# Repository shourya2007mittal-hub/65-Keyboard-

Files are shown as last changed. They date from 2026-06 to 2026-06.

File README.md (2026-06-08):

# 65-Keyboard-



I am building a 65% layout keyboard based on Seed Studio Xiao nrf52840 also It will have a 3.7v battery and an 0.91 inch OLED Screen. Switches will be HotSwapable. I used expander to connect the rows and coluns because there weren't enough pins available.

## Features
-  nrf52840 Rp2040
- uses 65% Keyboard Layout 
-  Uses Keyboard Matrix
-  Had a rotor encoder and an 0.91 inch oled screen

  | Item | Price | Source |
|------|------:|--------|
| PCB + Shipping - Coupons | 25.14 | JLCPCB |
| KeyCaps | 15.04 | https://meckeys.com/shop/accessories/keyboard-accessories/keycaps/gengar-anime-keycap-set/ |
| Hot-swap (pack of 10) × 7 | 5.50 | https://meckeys.com/shop/accessories/keyboard-accessories/key-switches/kailh-hot-swap-socket/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 |
| Switches (pack of 10) × 7 | 22.10 | https://meckeys.com/shop/accessories/keyboard-accessories/key-switches/hmx-xinhai-switch/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 |
| Stabilizers | 10.76 | https://meckeys.com/shop/accessories/keyboard-accessories/more/glorious-goat-stabilizers/ |
| Meckeys Shipping | 1.10 | https://meckeys.com |
| Expander × 2 | 6.22 | https://robu.in/product/pca9555dwr-texas-instruments-400khz-soic-24-300mil-i-o-expanders-rohs/ |
| XIAO BLE nRF52840 | 12.40 | https://robu.in/product/seeed-studio-xiao-ble-nrf52840/ |
| On-Off Switch | 1.12 | https://robu.in/product/os202011ma0qn1-ck-100ma-dpdt-12v-10000-times-plugin-slide-switches-rohs/ |
| 2MΩ Resistor | 0.13 | https://robu.in/product/crcw12062m20fkea-vishay-smd-chip-resistor-2-2-mohm-%c2%b1-1-250-mw-1206-3216-metric-thick-film-general-purpose/ |
| 806kΩ Resistor | 0.13 | https://robu.in/product/rc0402fr-07806kl-yageo-smd-chip-resistor-806-kohm-%c2%b1-1-63-mw-0402-1005-metric-thick-film-general-purpose/ |
| Robu Shipping | 1.10 | https://robu.in |
| Solder Paste for SMD Components | 2.70 | https://www.amazon.in/gp/product/B0GY879KCL/ |
| 1N4148W-T4 Diodes (Pack of 15) × 5 ( used amazon beacuse wasn't avilable anywhere else)| 11.78 | https://www.amazon.in/gp/product/B0FZL2D1GG/ |
| **Total** | **115.22** | |

### Schematic<br><br>



###  PCB Design<br><br>




### 3D Render <br><br>
Screenshot 2026-06-08 170318 - Copy




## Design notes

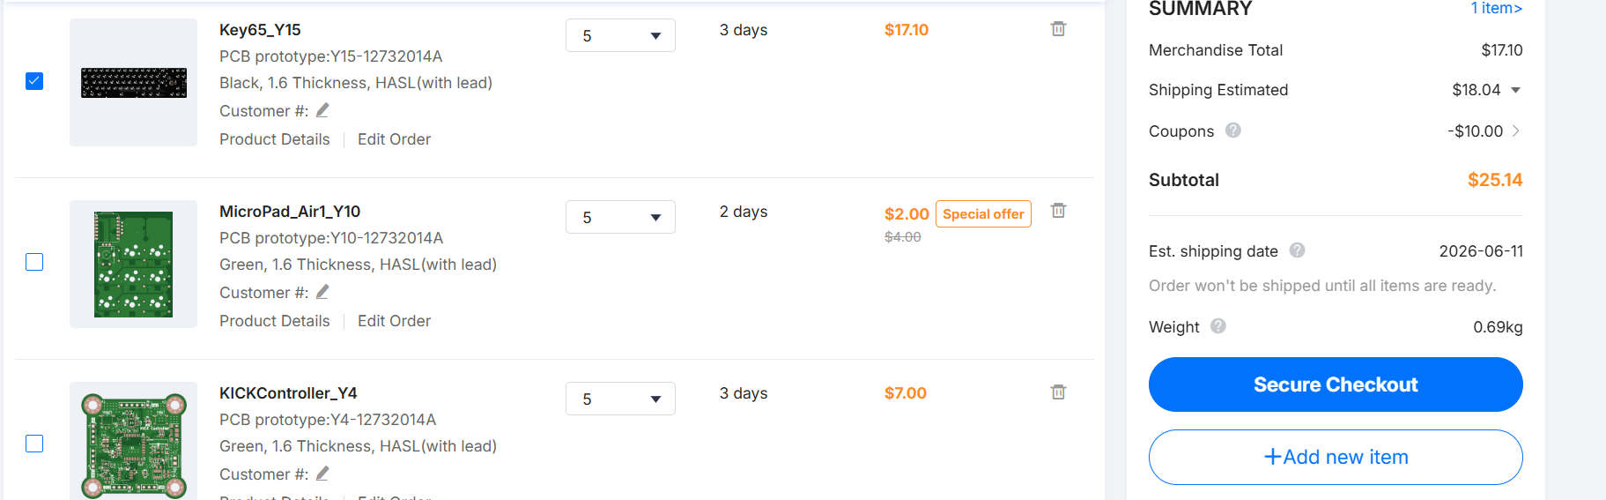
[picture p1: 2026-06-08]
Payout Screenshot/Screenshot 2026-06-08 213410.png

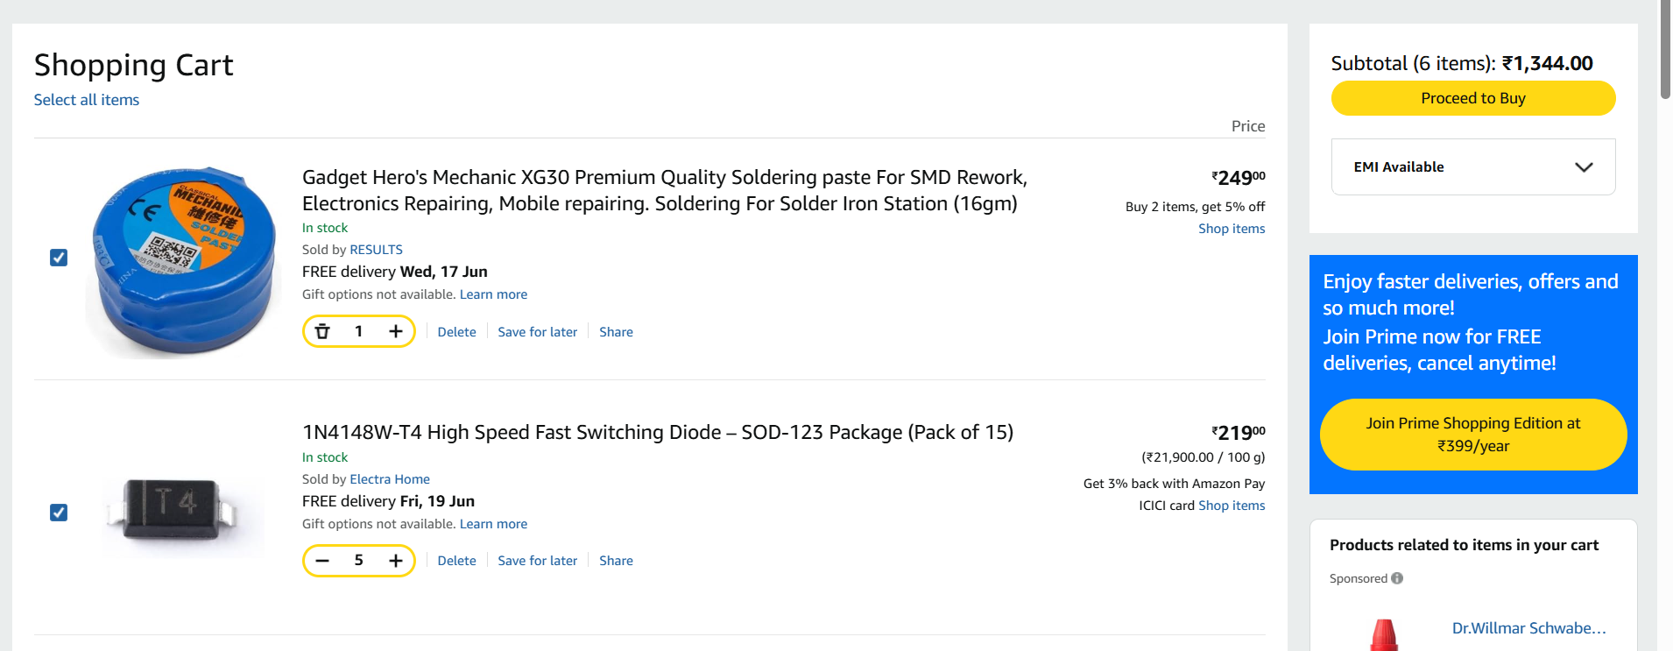
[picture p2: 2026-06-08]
Payout Screenshot/Screenshot 2026-06-08 214906.png

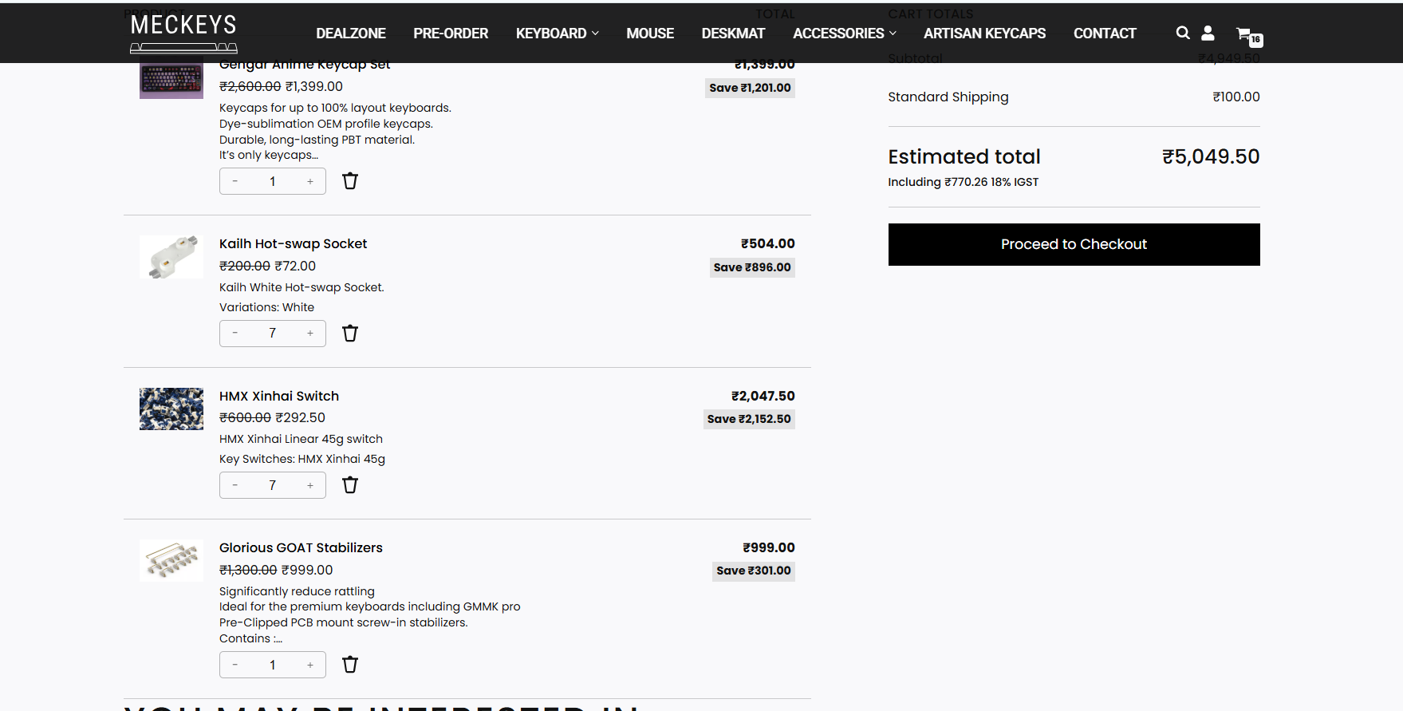
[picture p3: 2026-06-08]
Payout Screenshot/Screenshot 2026-06-08 215119.png

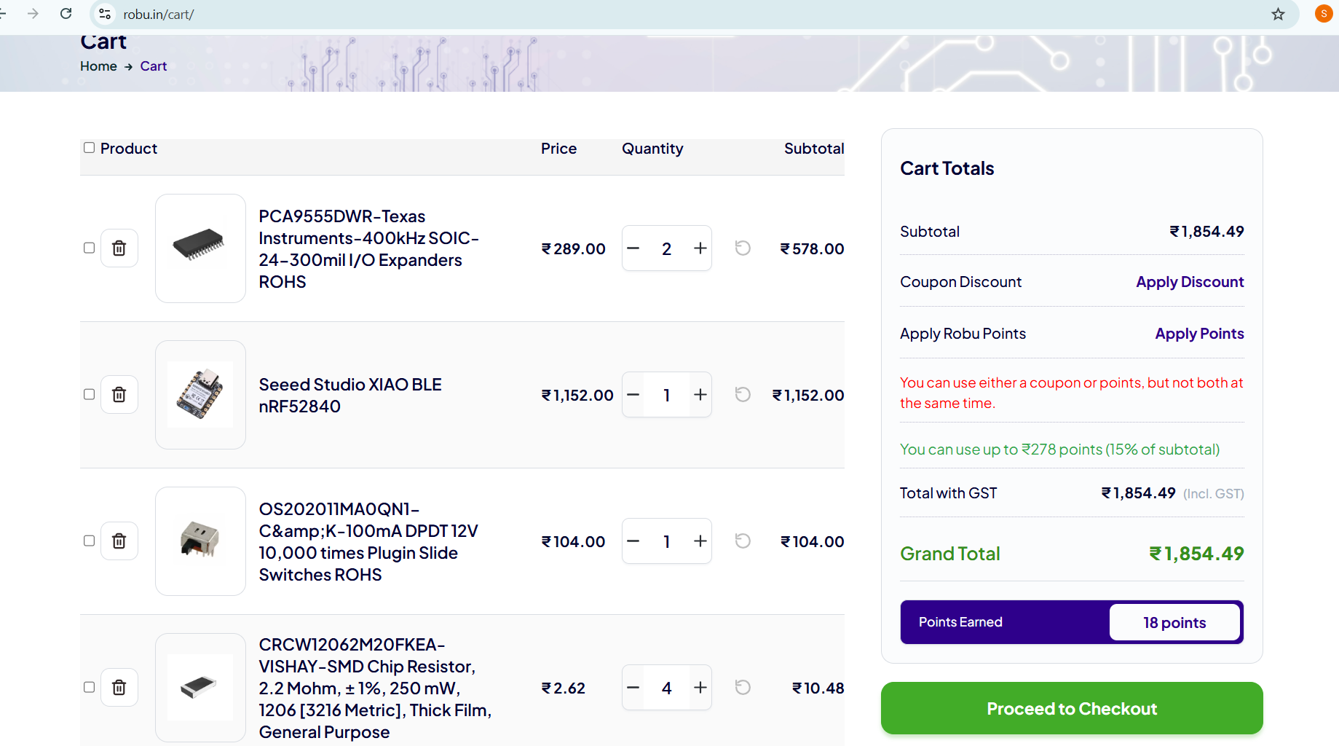
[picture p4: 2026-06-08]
Payout Screenshot/Screenshot 2026-06-08 215139.png

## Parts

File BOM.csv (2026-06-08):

Item | Price | Source
PCB + Shipping - Coupons | 25.14 | JLCPCB
KeyCaps | 15.04 | https://meckeys.com/shop/accessories/keyboard-accessories/keycaps/gengar-anime-keycap-set/
Hot-swap (pack of 10) x7 | 5.5 | https://meckeys.com/shop/accessories/keyboard-accessories/key-switches/kailh-hot-swap-socket/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
Switches (pack of 10) x 7 | 22.1 | https://meckeys.com/shop/accessories/keyboard-accessories/key-switches/hmx-xinhai-switch/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
Stabilizers | 10.76 | https://meckeys.com/shop/accessories/keyboard-accessories/more/glorious-goat-stabilizers/
Meckey shipping | 1.1 | meckeys.com
Expander x 2 | 6.22 | https://robu.in/product/pca9555dwr-texas-instruments-400khz-soic-24-300mil-i-o-expanders-rohs/
XIAO BLE nRF52840 | 12.4 | https://robu.in/product/seeed-studio-xiao-ble-nrf52840/
On-Off switch | 1.12 | https://robu.in/product/os202011ma0qn1-ck-100ma-dpdt-12v-10000-times-plugin-slide-switches-rohs/
2M OHM Resistor | 0.13 | https://robu.in/product/crcw12062m20fkea-vishay-smd-chip-resistor-2-2-mohm-%c2%b1-1-250-mw-1206-3216-metric-thick-film-general-purpose/
806k resistor | 0.13 | https://robu.in/product/rc0402fr-07806kl-yageo-smd-chip-resistor-806-kohm-%c2%b1-1-63-mw-0402-1005-metric-thick-film-general-purpose/
Robu shipping | 1.1 | robu.in
Solder Paste for SND components | 2.7 | https://www.amazon.in/gp/product/B0GY879KCL/ref=ox_sc_act_title_1?smid=A2TAUOL95KBX1X&psc=1
1N4148W-T4 diodes (Pack of 15) X 5 ( used amazon beacuse wasn't avilable anywhere else) | 11.78 | https://www.amazon.in/gp/product/B0FZL2D1GG/ref=ox_sc_act_title_2?smid=A28WR0HSDEABON&psc=1
Total | 115.2

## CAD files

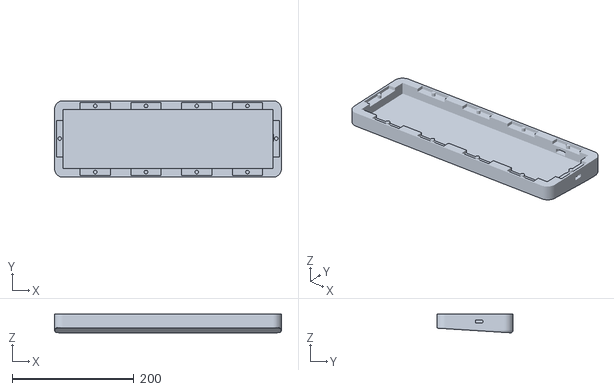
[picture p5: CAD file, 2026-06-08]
Production/Base.stl
372.9 x 125.6 x 30.8

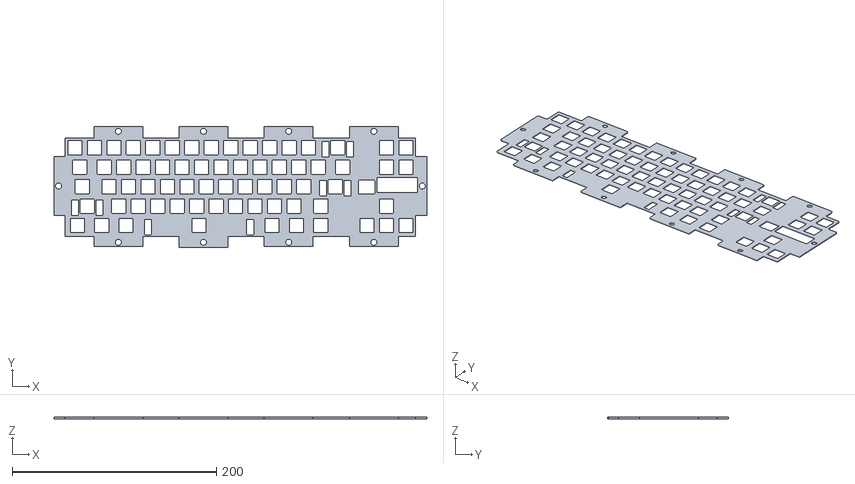
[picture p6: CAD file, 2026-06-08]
Production/Plate.stl
365.0 x 118.0 x 1.50

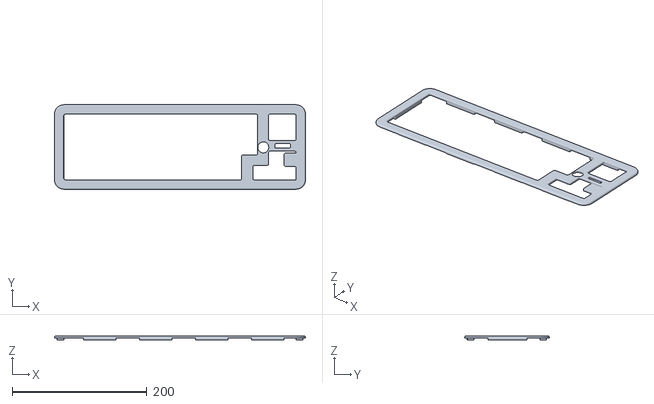
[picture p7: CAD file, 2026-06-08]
Production/Top.stl
372.9 x 125.6 x 6.50

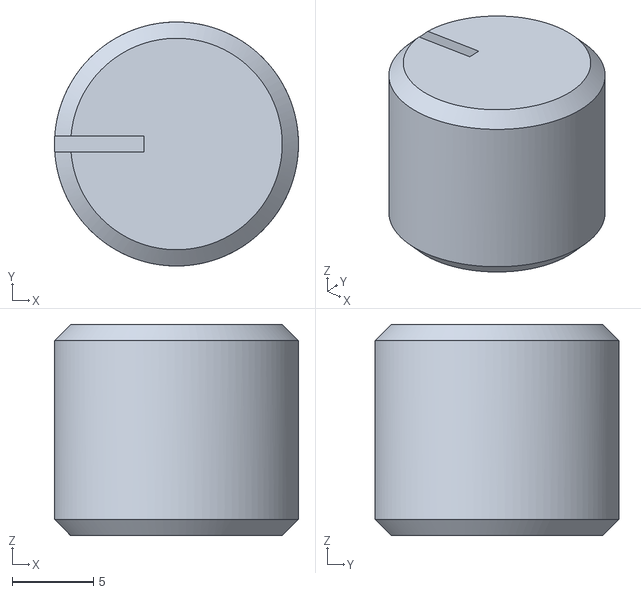
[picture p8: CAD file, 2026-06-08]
Production/Rotor Encoder.stl
15.0 x 15.0 x 13.0

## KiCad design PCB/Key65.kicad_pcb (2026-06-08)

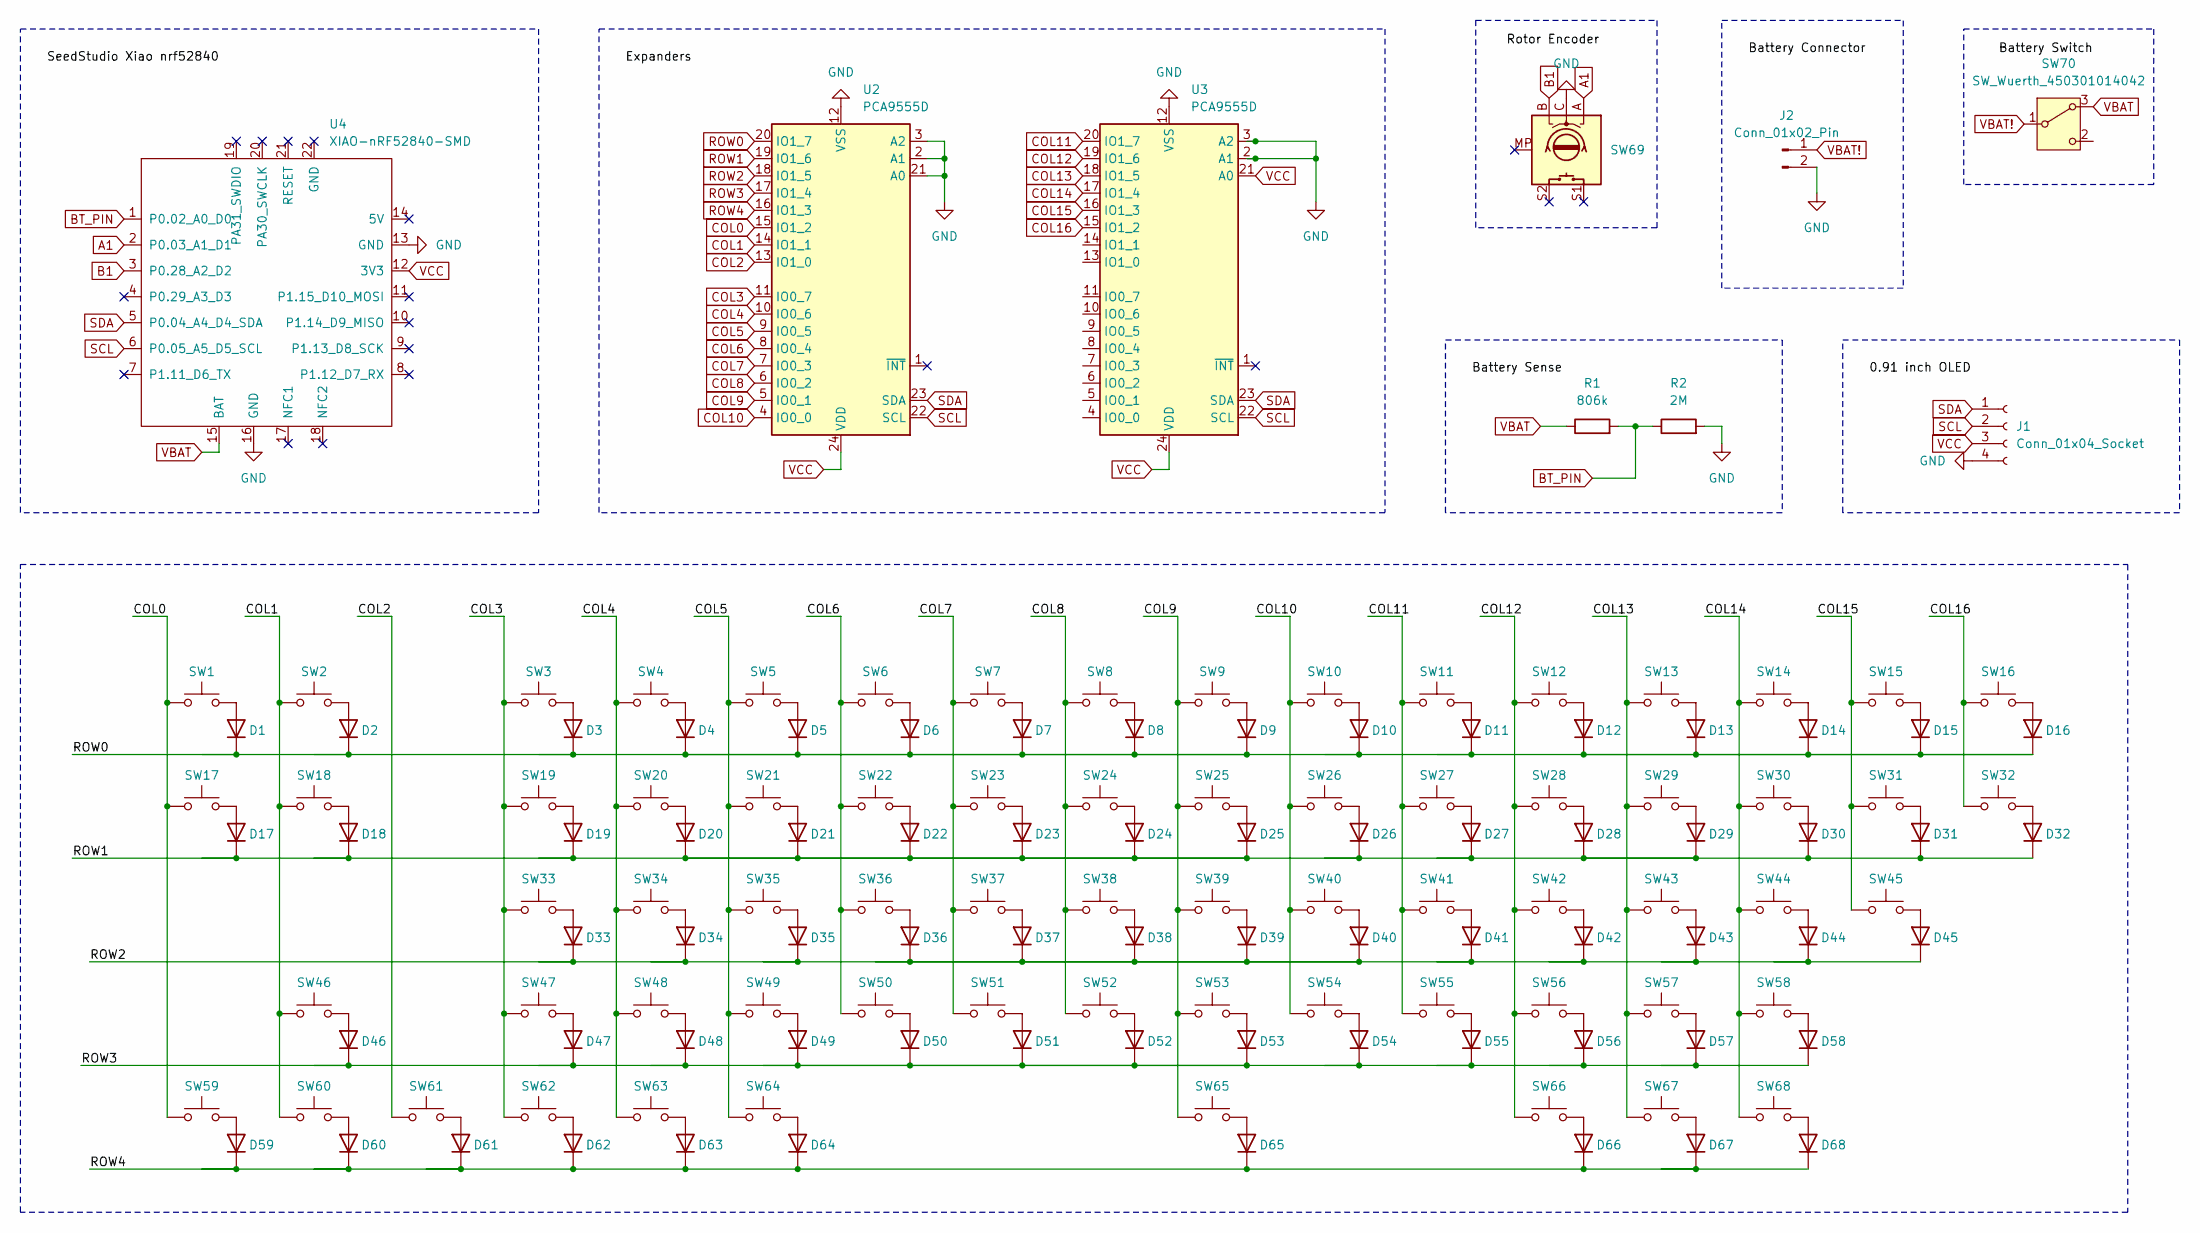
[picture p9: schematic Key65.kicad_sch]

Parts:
D1, D2, D3, D4, D5, D6, D7, D8, D9, D10, D11, D12, D13, D14, D15, D16, D17, D18, D19, D20, D21, D22, D23, D24, D25, D26, D27, D28, D29, D30, D31, D32, D33, D34, D35, D36, D37, D38, D39, D40, D41, D42, D43, D44, D45, D46, D47, D48, D49, D50, D51, D52, D53, D54, D55, D56, D57, D58, D59, D60, D61, D62, D63, D64, D65, D66, D67, D68: D; D_SOD-123
J1: Conn_01x04_Socket; PinHeader_1x04_P2.54mm_Vertical
J2: Conn_01x02_Pin; JST_JWPF_B02B-JWPF-SK-R_1x02_P2.00mm_Vertical
R1: 806k; R_0805_2012Metric
R2: 2M; R_0805_2012Metric
SW1, SW2, SW3, SW4, SW5, SW6, SW7, SW8, SW9, SW10, SW11, SW12, SW13, SW14, SW15, SW16, SW17, SW18, SW19, SW20, SW21, SW22, SW23, SW24, SW25, SW26, SW27, SW28, SW29, SW30, SW31, SW32, SW33, SW34, SW35, SW36, SW37, SW38, SW39, SW40, SW41, SW42, SW43, SW44, SW45, SW46, SW47, SW48, SW49, SW50, SW51, SW52, SW53, SW54, SW55, SW56, SW57, SW58, SW59, SW60, SW61, SW62, SW63, SW64, SW65, SW66, SW67, SW68: SW_Push; SW_MX_HS_CPG151101S11_1u
SW69: RotaryEncoder_Switch_MP; RotaryEncoder_Alps_EC11E-Switch_Vertical_H20mm
SW70: SW_Wuerth_450301014042; SW_Slide_SPDT_Straight_CK_OS102011MS2Q
U2, U3: PCA9555D; SOIC-24W_7.5x15.4mm_P1.27mm
U4: XIAO-nRF52840-SMD; modified-XIAO-nRF52840-SMD

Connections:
A1: SW69.A, U4.2 (P0.03_A1_D1)
B1: SW69.B, U4.3 (P0.28_A2_D2)
BT_PIN: R1.2, R2.1, U4.1 (P0.02_A0_D0)
COL0: SW1.1, SW17.1, SW59.1, U2.15 (IO1_2)
COL1: SW2.1, SW18.1, SW46.1, SW60.1, U2.14 (IO1_1)
COL2: SW61.1, U2.13 (IO1_0)
COL3: SW3.1, SW19.1, SW33.1, SW47.1, SW62.1, U2.11 (IO0_7)
COL4: SW4.1, SW20.1, SW34.1, SW48.1, SW63.1, U2.10 (IO0_6)
COL5: SW5.1, SW21.1, SW35.1, SW49.1, SW64.1, U2.9 (IO0_5)
COL6: SW6.1, SW22.1, SW36.1, SW50.1, U2.8 (IO0_4)
COL7: SW7.1, SW23.1, SW37.1, SW51.1, U2.7 (IO0_3)
COL8: SW8.1, SW24.1, SW38.1, SW52.1, U2.6 (IO0_2)
COL9: SW9.1, SW25.1, SW39.1, SW53.1, SW65.1, U2.5 (IO0_1)
COL10: SW10.1, SW26.1, SW40.1, SW54.1, U2.4 (IO0_0)
COL11: SW11.1, SW27.1, SW41.1, SW55.1, U3.20 (IO1_7)
COL12: SW12.1, SW28.1, SW42.1, SW56.1, SW66.1, U3.19 (IO1_6)
COL13: SW13.1, SW29.1, SW43.1, SW57.1, SW67.1, U3.18 (IO1_5)
COL14: SW14.1, SW30.1, SW44.1, SW58.1, SW68.1, U3.17 (IO1_4)
COL15: SW15.1, SW31.1, SW45.1, U3.16 (IO1_3)
COL16: SW16.1, SW32.1, U3.15 (IO1_2)
GND: J1.4, J2.2, R2.2, SW69.C, U2.2 (A1), U2.3 (A2), U2.12 (VSS), U2.21 (A0), U3.2 (A1), U3.3 (A2), U3.12 (VSS), U4.13 (GND), U4.16 (GND)
unnamed: D1.2 (A), SW1.2
unnamed: D2.2 (A), SW2.2
unnamed: D3.2 (A), SW3.2
unnamed: D4.2 (A), SW4.2
unnamed: D5.2 (A), SW5.2
unnamed: D6.2 (A), SW6.2
unnamed: D7.2 (A), SW7.2
unnamed: D8.2 (A), SW8.2
unnamed: D9.2 (A), SW9.2
unnamed: D10.2 (A), SW10.2
unnamed: D11.2 (A), SW11.2
unnamed: D12.2 (A), SW12.2
unnamed: D13.2 (A), SW13.2
unnamed: D14.2 (A), SW14.2
unnamed: D15.2 (A), SW15.2
unnamed: D16.2 (A), SW16.2
unnamed: D17.2 (A), SW17.2
unnamed: D18.2 (A), SW18.2
unnamed: D19.2 (A), SW19.2
unnamed: D20.2 (A), SW20.2
unnamed: D21.2 (A), SW21.2
unnamed: D22.2 (A), SW22.2
unnamed: D23.2 (A), SW23.2
unnamed: D24.2 (A), SW24.2
unnamed: D25.2 (A), SW25.2
unnamed: D26.2 (A), SW26.2
unnamed: D27.2 (A), SW27.2
unnamed: D28.2 (A), SW28.2
unnamed: D29.2 (A), SW29.2
unnamed: D30.2 (A), SW30.2
unnamed: D31.2 (A), SW31.2
unnamed: D32.2 (A), SW32.2
unnamed: D33.2 (A), SW33.2
unnamed: D34.2 (A), SW34.2
unnamed: D35.2 (A), SW35.2
unnamed: D36.2 (A), SW36.2
unnamed: D37.2 (A), SW37.2
unnamed: D38.2 (A), SW38.2
unnamed: D39.2 (A), SW39.2
unnamed: D40.2 (A), SW40.2
unnamed: D41.2 (A), SW41.2
unnamed: D42.2 (A), SW42.2
unnamed: D43.2 (A), SW43.2
unnamed: D44.2 (A), SW44.2
unnamed: D45.2 (A), SW45.2
unnamed: D46.2 (A), SW46.2
unnamed: D47.2 (A), SW47.2
unnamed: D48.2 (A), SW48.2
unnamed: D49.2 (A), SW49.2
unnamed: D50.2 (A), SW50.2
unnamed: D51.2 (A), SW51.2
unnamed: D52.2 (A), SW52.2
unnamed: D53.2 (A), SW53.2
unnamed: D54.2 (A), SW54.2
unnamed: D55.2 (A), SW55.2
unnamed: D56.2 (A), SW56.2
unnamed: D57.2 (A), SW57.2
unnamed: D58.2 (A), SW58.2
unnamed: D59.2 (A), SW59.2
unnamed: D60.2 (A), SW60.2
unnamed: D61.2 (A), SW61.2
unnamed: D62.2 (A), SW62.2
unnamed: D63.2 (A), SW63.2
unnamed: D64.2 (A), SW64.2
unnamed: D65.2 (A), SW65.2
unnamed: D66.2 (A), SW66.2
unnamed: D67.2 (A), SW67.2
unnamed: D68.2 (A), SW68.2
ROW0: D1.1 (K), D2.1 (K), D3.1 (K), D4.1 (K), D5.1 (K), D6.1 (K), D7.1 (K), D8.1 (K), D9.1 (K), D10.1 (K), D11.1 (K), D12.1 (K), D13.1 (K), D14.1 (K), D15.1 (K), D16.1 (K), U2.20 (IO1_7)
ROW1: D17.1 (K), D18.1 (K), D19.1 (K), D20.1 (K), D21.1 (K), D22.1 (K), D23.1 (K), D24.1 (K), D25.1 (K), D26.1 (K), D27.1 (K), D28.1 (K), D29.1 (K), D30.1 (K), D31.1 (K), D32.1 (K), U2.19 (IO1_6)
ROW2: D33.1 (K), D34.1 (K), D35.1 (K), D36.1 (K), D37.1 (K), D38.1 (K), D39.1 (K), D40.1 (K), D41.1 (K), D42.1 (K), D43.1 (K), D44.1 (K), D45.1 (K), U2.18 (IO1_5)
ROW3: D46.1 (K), D47.1 (K), D48.1 (K), D49.1 (K), D50.1 (K), D51.1 (K), D52.1 (K), D53.1 (K), D54.1 (K), D55.1 (K), D56.1 (K), D57.1 (K), D58.1 (K), U2.17 (IO1_4)
ROW4: D59.1 (K), D60.1 (K), D61.1 (K), D62.1 (K), D63.1 (K), D64.1 (K), D65.1 (K), D66.1 (K), D67.1 (K), D68.1 (K), U2.16 (IO1_3)
SCL: J1.2, U2.22 (SCL), U3.22 (SCL), U4.6 (P0.05_A5_D5_SCL)
SDA: J1.1, U2.23 (SDA), U3.23 (SDA), U4.5 (P0.04_A4_D4_SDA)
VBAT: R1.1, SW70.3 (A), U4.15 (BAT)
VBAT!: J2.1, SW70.1 (B)
VCC: J1.3, U2.24 (VDD), U3.21 (A0), U3.24 (VDD), U4.12 (3V3)

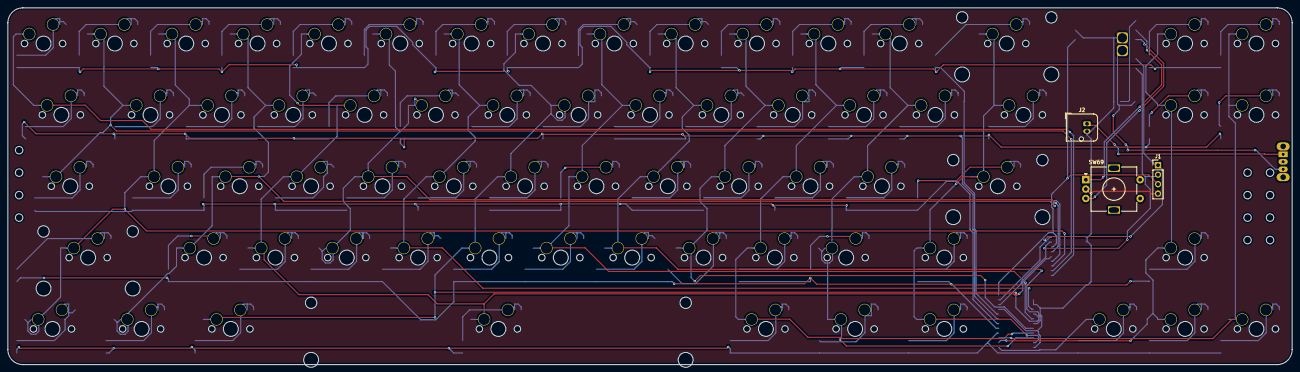
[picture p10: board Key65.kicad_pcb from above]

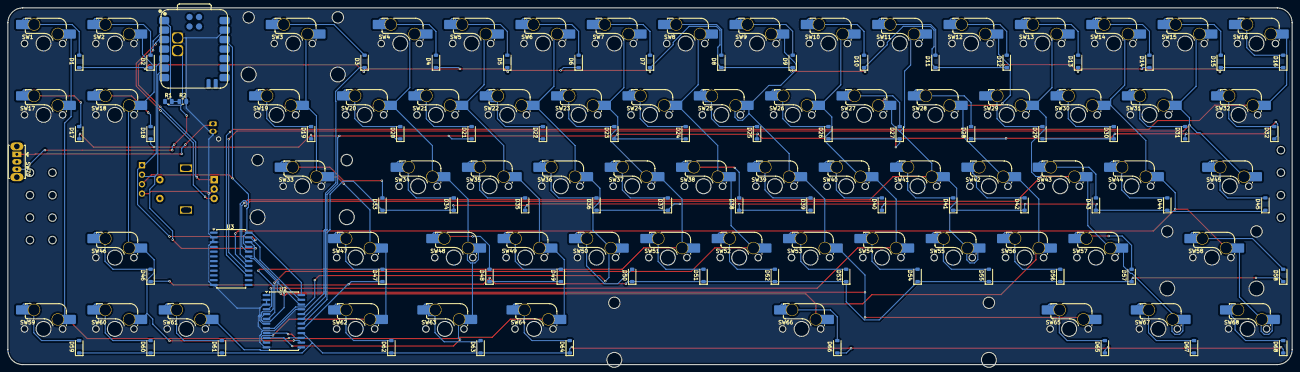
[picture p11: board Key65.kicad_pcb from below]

Board: 2 copper layers, 342.9 x 95.2 mm, 149 parts (142 on the bottom side), 99 nets.

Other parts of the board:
S1: STAB_MX_2u
S2, S3: STAB_MX_2.25u
S4: STAB_MX_6.25u

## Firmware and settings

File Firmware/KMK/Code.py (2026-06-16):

import board
from kmk.kmk_keyboard import KMKKeyboard
from kmk.keys import KC
from kmk.scanners import DiodeOrientation
from kmk.modules.layers import Layers

keyboard = KMKKeyboard()
keyboard.modules.append(Layers())

# ===== MATRIX PINS (MATCH YOUR SCHEMATIC) =====
keyboard.row_pins = (
    board.GP26,
    board.GP27,
    board.GP28,
    board.GP29,
    board.GP6,
)

keyboard.col_pins = (
    board.GP0,
    board.GP1,
    board.GP2,
    board.GP3,
    board.GP4,
    board.GP5,
    board.GP7,
    board.GP8,
    board.GP9,
    board.GP10,
    board.GP11,
    board.GP12,
    board.GP13,
    board.GP14,
)

keyboard.diode_orientation = DiodeOrientation.COLUMNS

# ===== KEYMAP =====
keyboard.keymap = [
    [
        KC.ESC, KC.N1, KC.N2, KC.N3, KC.N4, KC.N5, KC.N6, KC.N7, KC.N8, KC.N9, KC.N0, KC.MINS, KC.EQL, KC.BSPC,
        KC.TAB, KC.Q,  KC.W,  KC.E,  KC.R,  KC.T,  KC.Y,  KC.U,  KC.I,  KC.O,  KC.P,  KC.LBRC, KC.RBRC, KC.BSLS,
        KC.CAPS,KC.A,  KC.S,  KC.D,  KC.F,  KC.G,  KC.H,  KC.J,  KC.K,  KC.L,  KC.SCLN, KC.QUOT, KC.ENT,
        KC.LSFT,KC.Z,  KC.X,  KC.C,  KC.V,  KC.B,  KC.N,  KC.M,  KC.COMM,KC.DOT, KC.SLSH, KC.RSFT,
        KC.LCTL,KC.LGUI,KC.LALT,KC.SPC,KC.RALT,KC.RGUI,KC.MO(1),KC.RCTL
    ],
    [
        KC.GRV, KC.F1, KC.F2, KC.F3, KC.F4, KC.F5, KC.F6, KC.F7, KC.F8, KC.F9, KC.F10, KC.F11, KC.F12, KC.DEL,
        KC.NO,  KC.NO, KC.UP, KC.NO, KC.NO, KC.NO, KC.NO, KC.NO, KC.NO, KC.NO, KC.NO, KC.NO, KC.NO, KC.NO,
        KC.NO, KC.LEFT,KC.DOWN,KC.RIGHT,KC.NO,KC.NO,KC.NO,KC.NO,KC.NO,KC.NO,KC.NO,KC.NO,KC.NO,
        KC.NO, KC.NO, KC.NO, KC.NO, KC.NO, KC.NO, KC.NO, KC.NO, KC.NO, KC.NO, KC.NO, KC.NO,
        KC.NO, KC.NO, KC.NO, KC.NO, KC.NO, KC.NO, KC.NO, KC.NO
    ]
]

if __name__ == '__main__':
    keyboard.go()
